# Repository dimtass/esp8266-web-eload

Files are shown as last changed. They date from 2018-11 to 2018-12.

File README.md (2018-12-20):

esp8266-web-eload
---
This project is how to build an electronic load with a web interface
by using the esp8266-E12 module and some other electronic components.
This version is using the Arduino ESP8266 for simplicity, but I would
like to make this soon also baremetal and use the ESP API instead.

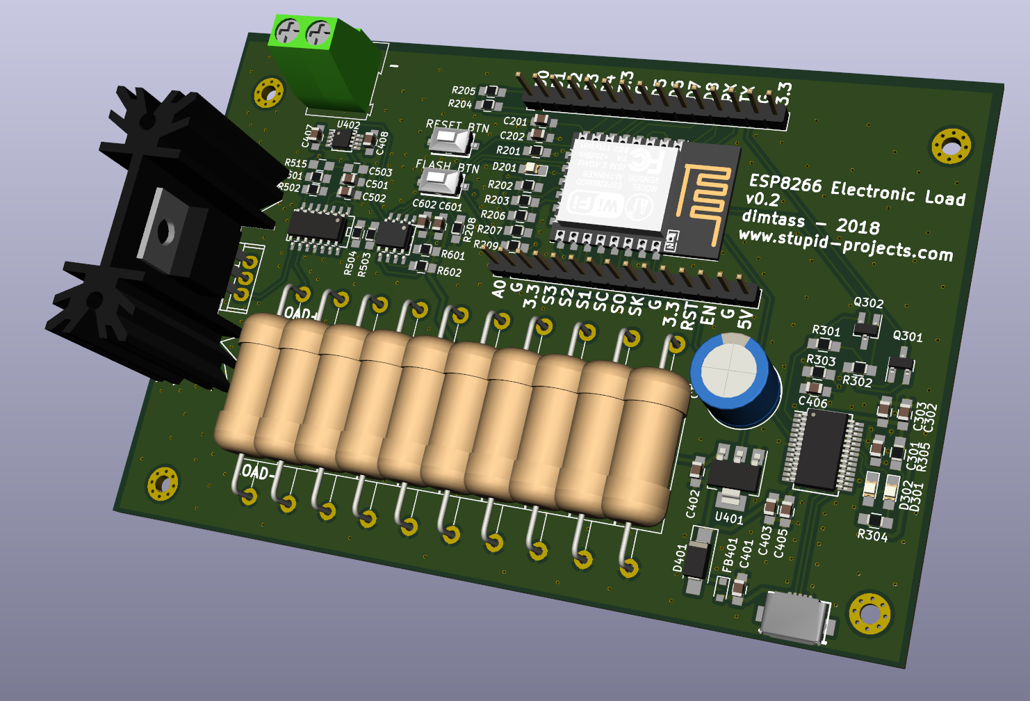
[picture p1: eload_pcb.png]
Electronic load board


## Board
You can also find the scematics to build a small pcb for that.
As you may already know, the esp8266 has a 10-bit ADC, but it lacks
a DAC. Therefore, we need an external SPI DAC. You can use any DAC
but as it is a home-project I prefer to use a bit more expensive
components.

The main components I've used are:
* `FDP6030BL`: N-Channel Logic Level MOSFET. This mosfet is features
40A, 30V, Rds(on)=0.024Ω @ Vgs=4.5V, 175oC max junction temp
* `MCP4821`: 12-bit SPI DAC with an internal Vref. This one has an
internal 2.048V reference and a 2x gain, therefore the Vref can be
up to 4.096V with a great accuracy. This means that we can drive the
Vgs on the MOSFET up to 4.096V, which means up to 4A with 1Ω load
resistor. If you need more current, then you can use the `MCP4921`
opamp which has an external reference, but that also means that you
need to provide a very clean and stable reference, too.
* `MCP6H04`: 4x single-supply, rail-to-rail opamp. This IC has four
opamps in the case. One is used to multiply the DAC output by a factor
of 2.2. One is used to drive the MOSFET and another one to buffer
the negative feedback loop to drive the ADC via a low pass RC filter
and a voltage divider with a 1/10 ratio.
* `FT232RL`: A USB to serial IC that is used for two reasons. One
is to power the circuit with 5V from the USB and the other is to
flash the esp8266. You need an IC that also has the DTR/RTS signals
in order to reset the board and put it into flash mode.

The DAC is 12-bit and it can take values 0-2.048V when the gain
is set to 1x or 0-4.096V when the gain is 2x. Also the ADC is 10-bits
with max input voltage 3V3, therefore it has 1024 steps. This means
that you need to use a voltage divider to feed the ADC.

## Build
You need to have the arduino IDE installed. I'm using Linux, so I'm
describing how to do that on Linux. First, download the IDE from
[here](https://www.arduino.cc/en/Main/Software). I usually prefer
specific versions because arduino IDE versions are known to be
incopatible with each other and some commands may not work between
versions. Therefore, for this project prefer to use version `1.8.6`
from [here](https://www.arduino.cc/download_handler.php?f=/arduino-1.8.6-linux64.tar.xz).
This is the x86_64 Linux version.

Extract the contents somewhere. I prefer `/opt`, for example
`/opt/arduino-1.8.6`.

Then open a console and run these commands:
```sh
mkdir -p ~/Arduino/hardware/esp8266com
cd ~/Arduino/hardware/esp8266com
git clone https://github.com/esp8266/Arduino.git esp8266
cd esp8266/tools
python get.py
/opt/arduino-1.8.6/arduino --install-boards esp8266:esp8266 --save-prefs
```

Then run the Arduino IDE and click `Tools -> Manage Libraries` and search
for the `websockets by Markus Sattler` library and select version `2.1.1`.
Then exit the Arduino IDE and from the source code folder run:
```sh
./build.sh
```

If your arduino IDE is not installed in `/opt/arduino-1.8.6` or you're
using a different version then you need to edit the `build.sh` script
and change the `ARDUINO=` variable with the correct path.

If everything goes right then you should have a folder named `build` and
inside that fodler a file named `esp8266-web-eload.ino.bin`.

Then connect you esp8266-E12 board with a USB cable on your computer and
verify which port is enumerated on it
```sh
dmesg | grep tty
```

Usually it will be the last port listed after you run the above command.

Finally, run the `upload-http-files.sh` script with the port you've found:
```sh
./upload-http-files.sh /dev/ttyUSB0
```

You might need to change the paths of the `mkspiffs` and `esptool` for the
script to work properly. If you want to be able to upload the web interface
from the Arduino IDE, then have a look to this plugin [here](https://github.com/esp8266/arduino-esp8266fs-plugin).
This will integrate this functionality in the IDE. I'm using the script
as it flashes everything on one go, but for development you don't have
to upload everything, so if you just change something in the code and the
web interface remains the same or the opposite, then better use the IDE.

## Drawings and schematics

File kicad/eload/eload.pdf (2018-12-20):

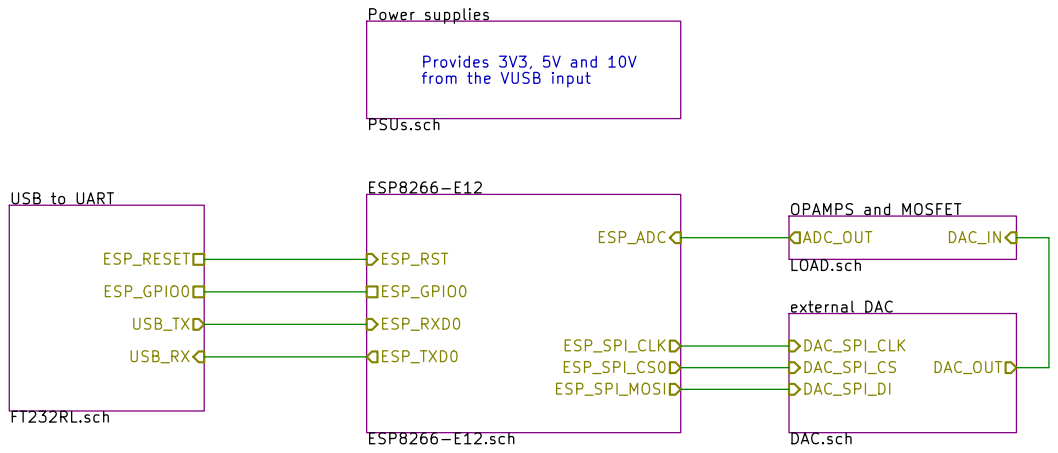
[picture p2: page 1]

from the VUSB input

This project uses a USB powered ESP8266, a DAC, a few opamps
and a N-MOSFET to create an electronic load. The source code
is available at:

Id: 1/6 Title: File: eload.sch Sheet: /
Electronic load using an ESP8266 and external DAC

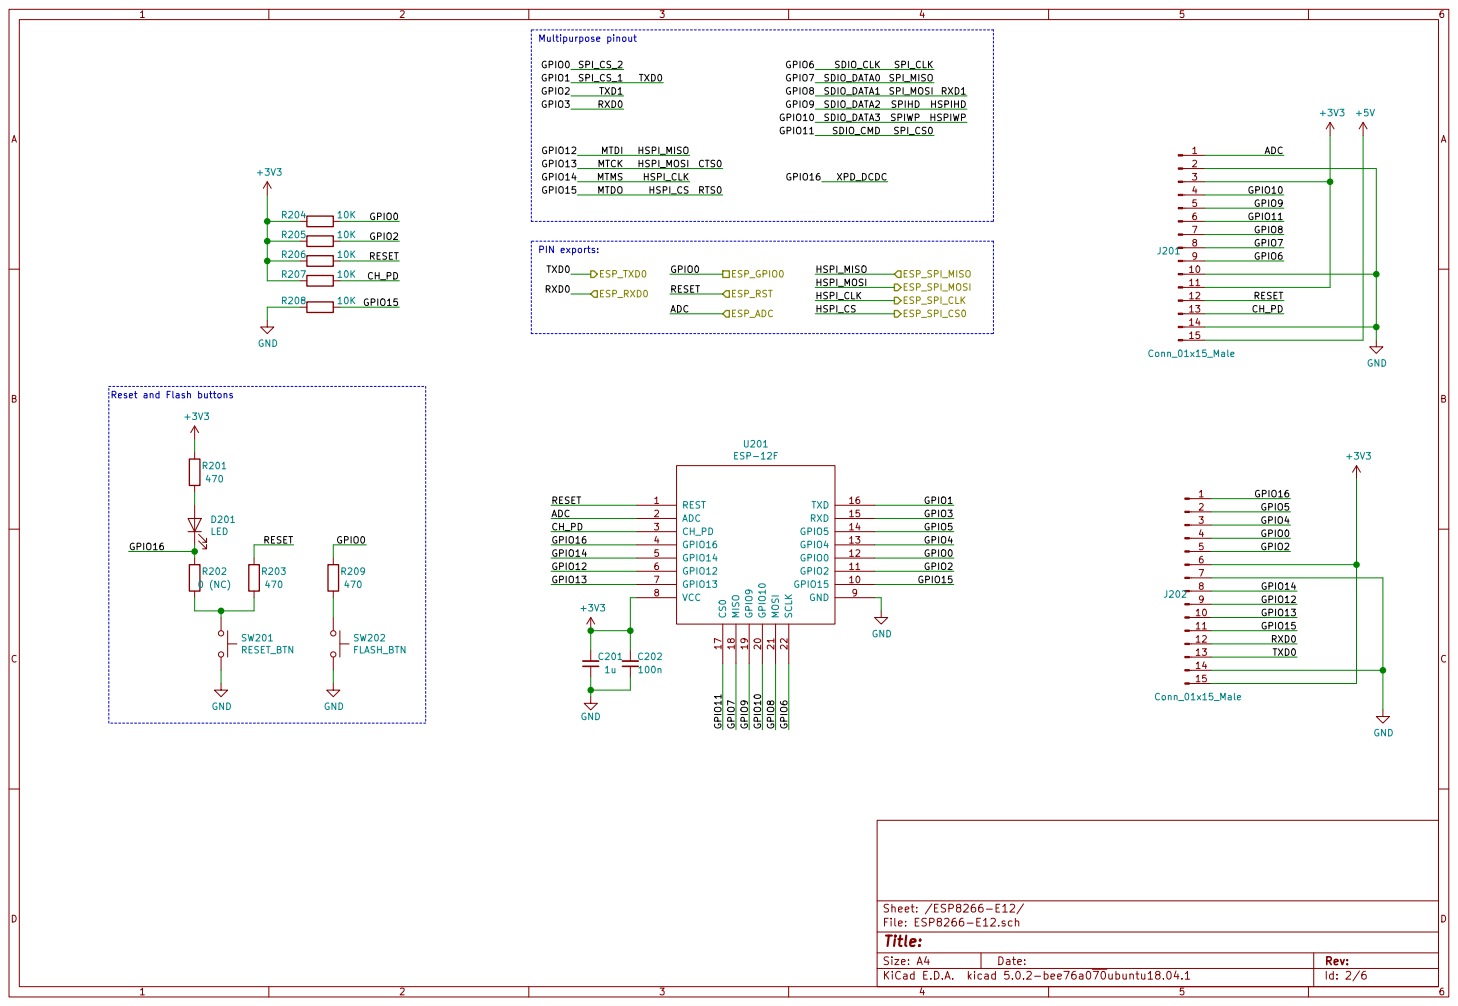
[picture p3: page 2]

Id: 2/6 Title: File: ESP8266-E12.sch Sheet: /ESP8266-E12/

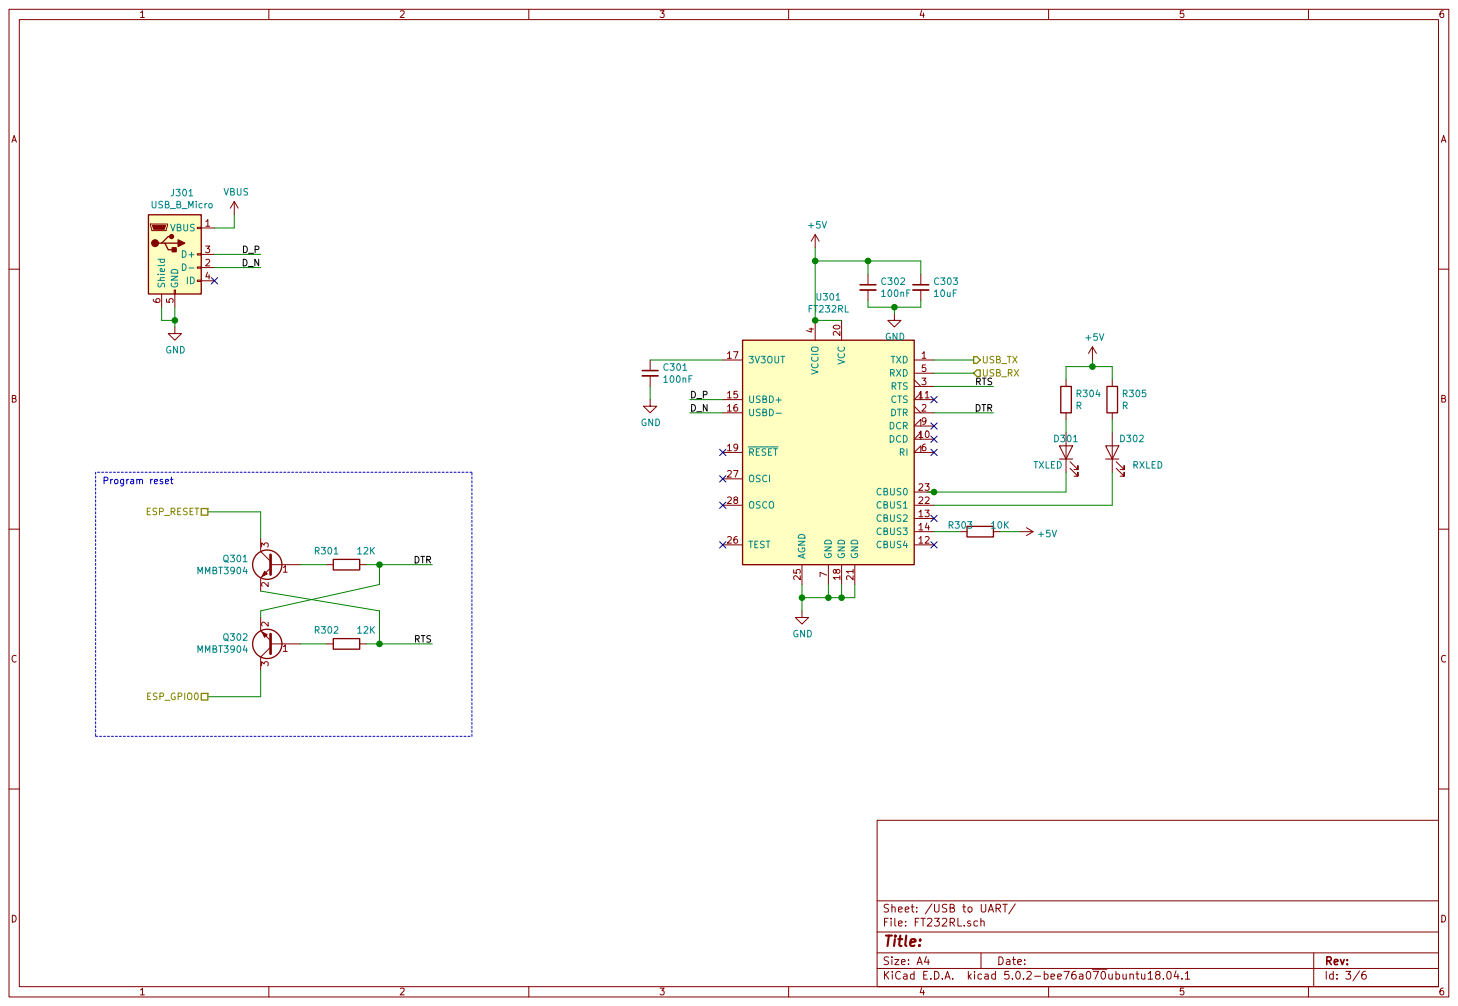
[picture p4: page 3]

Id: 3/6 Title: File: FT232RL.sch Sheet: /USB to UART/

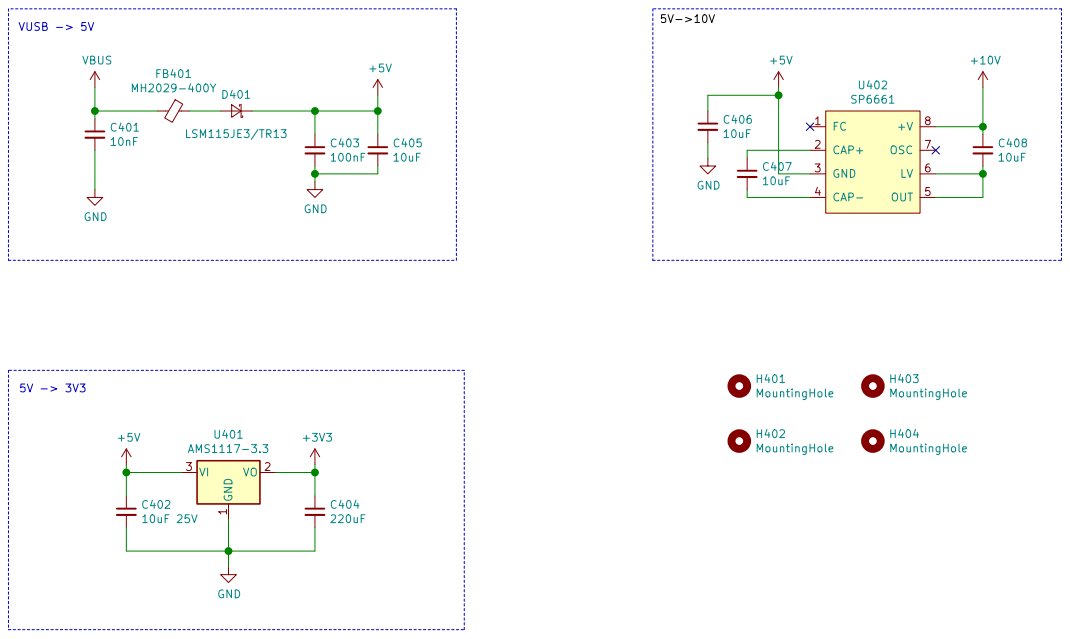
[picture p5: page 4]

Id: 4/6 Title: File: PSUs.sch Sheet: /Power supplies/

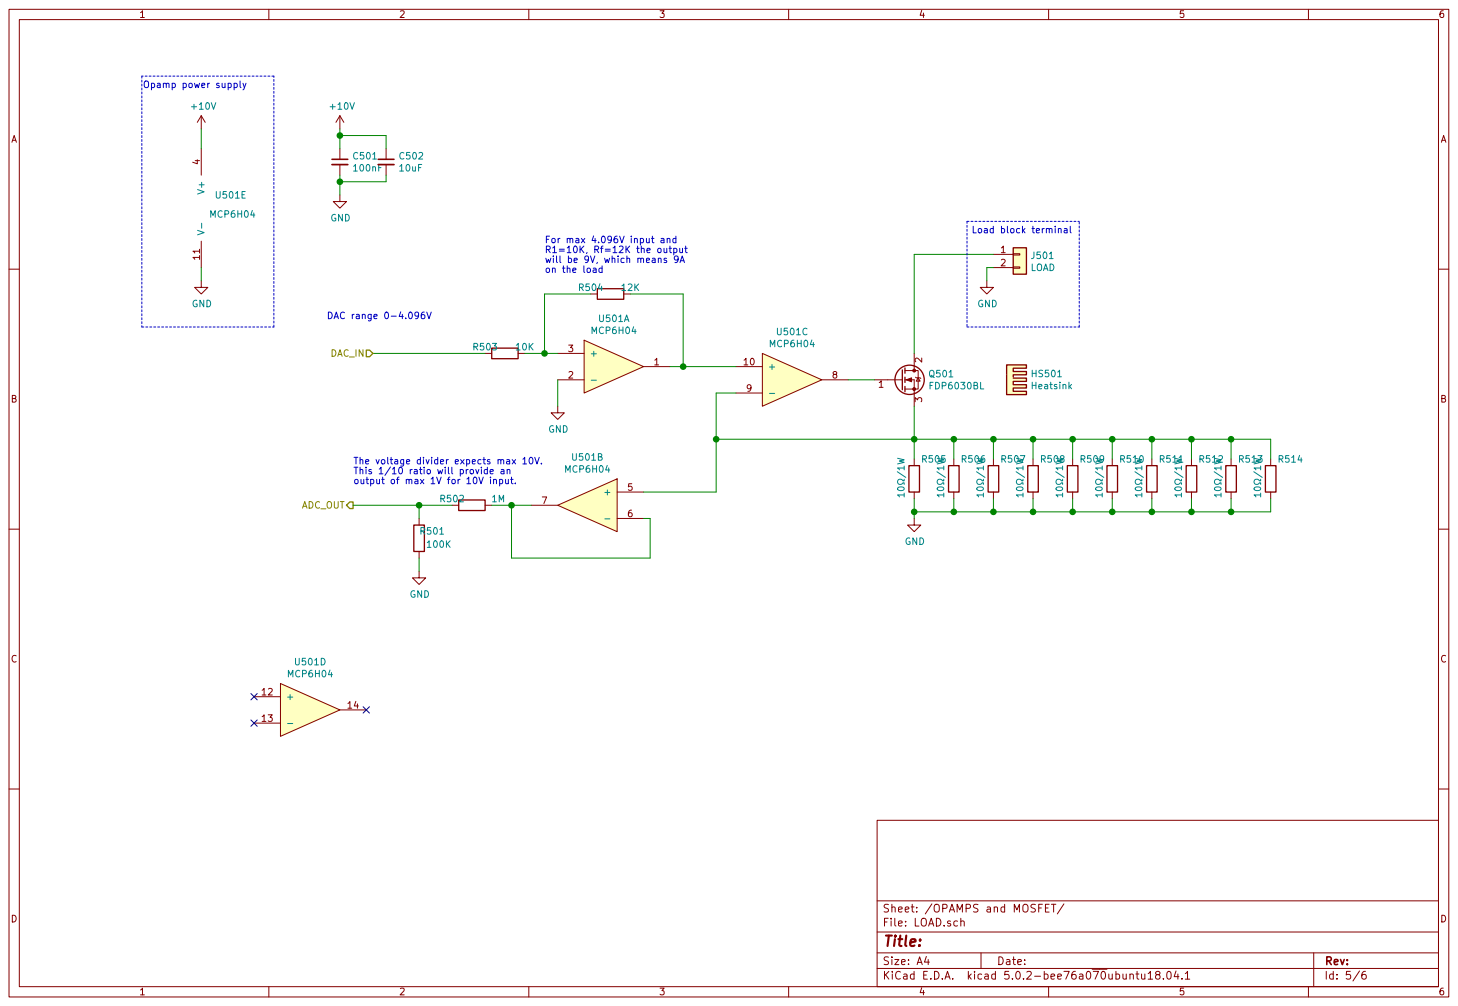
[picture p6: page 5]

Load block terminal DAC range 0-4.096V

For max 4.096V input and
R1=10K, Rf=12K the output will be 9V, which means 9A

The voltage divider expects max 10V.
This 1/10 ratio will provide an

Id: 5/6 Title: File: LOAD.sch Sheet: /OPAMPS and MOSFET/

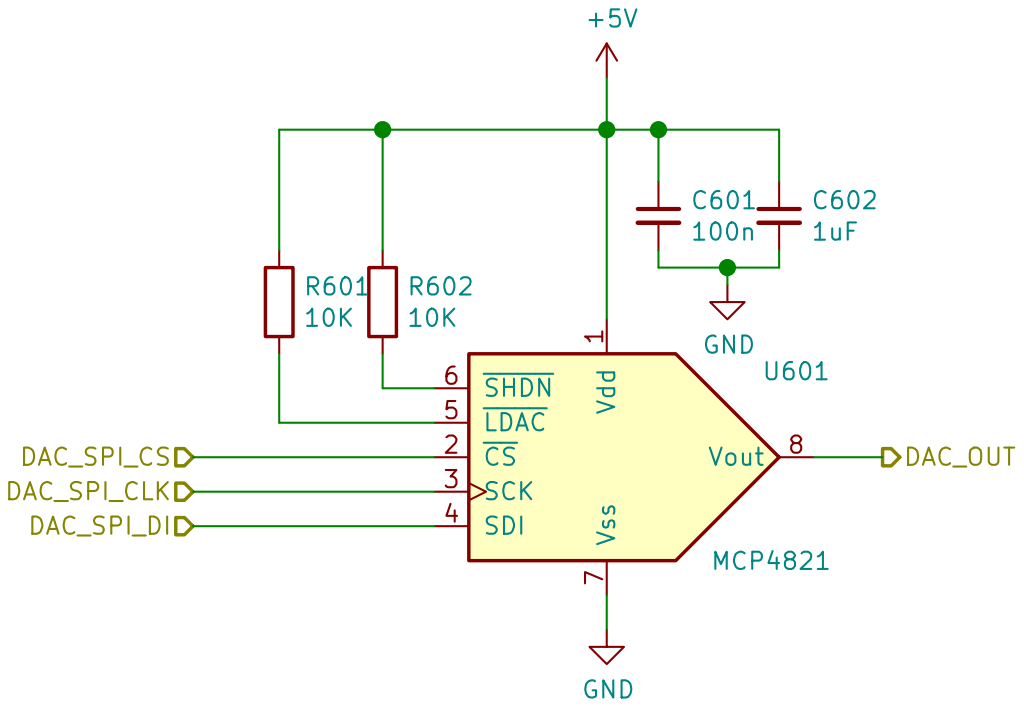
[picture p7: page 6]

Id: 6/6 Title: File: DAC.sch Sheet: /external DAC/ Vdd

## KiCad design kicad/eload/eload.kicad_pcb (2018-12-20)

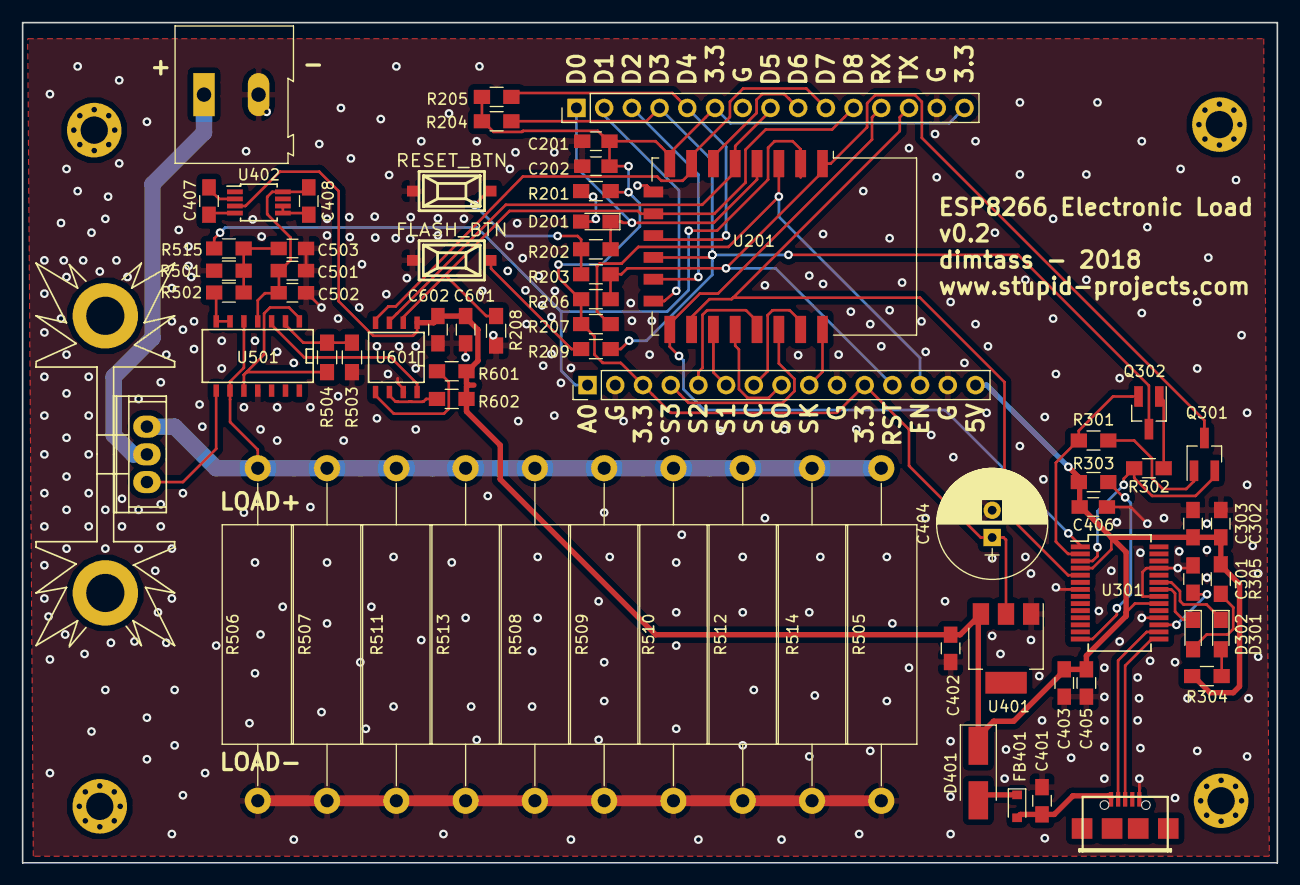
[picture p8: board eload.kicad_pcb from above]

Board: 2 copper layers, 115.0 x 77.0 mm, 74 parts (0 on the bottom side), 54 nets.

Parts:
C201: 1u; C_0805_HandSoldering
C202, C601: 100n; C_0805_HandSoldering
C301, C302, C403, C501: 100nF; C_0805_HandSoldering
C303, C405, C406, C407, C408, C502, C503: 10uF; C_0805_HandSoldering
C401: 10nF; C_0805_HandSoldering
C402: 10uF 25V; C_0805_HandSoldering
C404: 220uF; CP_Radial_D10.0mm_P2.50mm
C602: 1uF; C_0805_HandSoldering
D201: LED; LED_0805_HandSoldering
D301: TXLED; LED_0805_HandSoldering
D302: RXLED; LED_0805_HandSoldering
D401: LSM115JE3/TR13; D_SMA_Handsoldering
FB401: MH2029-400Y; D_0805
H401, H402, H403, H404: MountingHole; MountingHole_2.5mm_Pad_Via
HS501: Heatsink; Heatsink_Fischer_SK104-STCB_35x13mm__2xDrill3.5mm_ScrewM3
J201, J202: Conn_01x15_Male; Pin_Header_Straight_1x15_Pitch2.54mm
J301: USB_B_Micro; conn_usb_B_micro_smd-3
J501: LOAD; TerminalBlock_Altech_AK300-2_P5.00mm
Q301, Q302: MMBT3904; SOT-23_Handsoldering
Q501: FDP6030BL; TO-220
R201, R203, R209: 470; R_0805_HandSoldering
R202: 0 (NC); R_0805_HandSoldering
R204, R205, R206, R207, R208, R303, R502, R503, R601, R602: 10K; R_0805_HandSoldering
R301, R302, R504: 12K; R_0805_HandSoldering
R304, R305: R; R_0805_HandSoldering
R501: 1K; R_0805_HandSoldering
R505, R506, R507, R508, R509, R510, R511, R512, R513, R514: 10Ω/1W; R_Axial_Power_L20.0mm_W6.4mm_P30.48mm
R515: 15K; R_0805_HandSoldering
SW201: RESET_BTN; smd_push
SW202: FLASH_BTN; smd_push
U201: ESP-12F; ESP-12E
U301: FT232RL; SSOP-28_5.3x10.2mm_Pitch0.65mm
U401: AMS1117-3.3; SOT-223
U402: SP6661; MSOP-8_3x3mm_Pitch0.65mm
U501: MCP6H04; SOIC-14_N
U601: MCP4821; SOIC-8-N

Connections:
+3V3: C201.2, C202.2, C404.1, J201.3, J201.11, J202.6, J202.15, R201.1, R204.2, R205.2, R206.2, R207.2, U201.8, U401.2
+5V: C302.1, C303.1, C402.1, C403.1, C405.1, C406.1, C601.1, C602.1, D401.1, J201.15, R303.1, R304.1, R305.1, R601.1, R602.1, U301.4, U301.20, U401.3, U402.3, U601.1
+10V: C408.1, C501.1, C502.1, U402.8, U501.4
/ESP8266-E12/CH_PD: J201.13, R207.1, U201.3
/ESP8266-E12/ESP_GPIO0: J202.4, Q302.3, R204.1, R209.1, U201.12
/ESP8266-E12/ESP_RXD0: J202.12, U201.15, U301.1
/ESP8266-E12/ESP_SPI_MISO: J202.9, U201.6
/ESP8266-E12/ESP_TXD0: J202.13, U201.16, U301.5
/ESP8266-E12/GPIO2: J202.5, R205.1, U201.11
/ESP8266-E12/GPIO4: J202.3, U201.13
/ESP8266-E12/GPIO5: J202.2, U201.14
/ESP8266-E12/GPIO6: J201.9, U201.22
/ESP8266-E12/GPIO7: J201.8, U201.18
/ESP8266-E12/GPIO8: J201.7, U201.21
/ESP8266-E12/GPIO9: J201.5, U201.19
/ESP8266-E12/GPIO10: J201.4, U201.20
/ESP8266-E12/GPIO11: J201.6, U201.17
/ESP8266-E12/GPIO16: D201.1, J202.1, R202.1, U201.4
/OPAMPS and MOSFET/ADC_OUT: J201.1, R515.2, U201.2
/OPAMPS and MOSFET/DAC_IN: U501.3, U601.8
/USB to UART/DTR: Q302.2, R301.2, U301.2
/USB to UART/D_N: J301.2, U301.16
/USB to UART/D_P: J301.3, U301.15
/USB to UART/ESP_RESET: J201.12, Q301.3, R203.1, R206.1, U201.1
/USB to UART/RTS: Q301.2, R302.2, U301.3
/external DAC/DAC_SPI_CLK: J202.8, U201.5, U601.3
/external DAC/DAC_SPI_CS: J202.11, R208.1, U201.10, U601.2
/external DAC/DAC_SPI_DI: J202.10, U201.7, U601.4
GND: C201.1, C202.1, C301.2, C302.2, C303.2, C401.2, C402.2, C403.2, C404.2, C405.2, C406.2, C501.2, C502.2, C503.2, C601.2, C602.2, J201.2, J201.10, J201.14, J202.7, J202.14, J301.5, J501.2, R208.2, R501.1, R503.2, R505.2, R506.2, R507.2, R508.2, R509.2, R510.2, R511.2, R512.2, R513.2, R514.2, SW201.2, SW202.2, U201.9, U301.7, U301.18, U301.21, U301.25, U401.1, U501.11, U601.7
unnamed: C301.1, U301.17
unnamed: C407.1, U402.2
unnamed: C407.2, U402.4
unnamed: C408.2, U402.5, U402.6
unnamed: C503.1, R501.2, R502.2, R515.1
unnamed: D201.2, R201.2
unnamed: D301.1, U301.23
unnamed: D301.2, R304.2
unnamed: D302.1, U301.22
unnamed: D302.2, R305.2
unnamed: D401.2, FB401.1
unnamed: J501.1, Q501.2
unnamed: Q301.1, R301.1
unnamed: Q302.1, R302.1
unnamed: Q501.1, U501.8
unnamed: Q501.3, R505.1, R506.1, R507.1, R508.1, R509.1, R510.1, R511.1, R512.1, R513.1, R514.1, U501.5, U501.9
unnamed: R202.2, R203.2, SW201.1
unnamed: R209.2, SW202.1
unnamed: R303.2, U301.14
unnamed: R502.1, U501.6, U501.7
unnamed: R503.1, R504.2, U501.2
unnamed: R504.1, U501.1, U501.10
unnamed: R601.2, U601.5
unnamed: R602.2, U601.6
VBUS: C401.1, FB401.2, J301.1

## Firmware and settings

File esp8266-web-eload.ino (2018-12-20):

#include "Arduino.h"
#include <WebSocketsServer.h>
#include <FS.h>
#include <SPI.h>
#include "HelperFunctions.h"

int adc_value = 0;
int adc_acc = 0;
int acc = 0;
String inData;


//The setup function is called once at startup of the sketch
void setup()
{
	Serial.begin(115200);
	delay(1000);
	SPIFFS.begin();
	Serial.println(); Serial.print("Configuring access point...");
	setupWiFi();
	IPAddress myIP = WiFi.softAPIP();
	Serial.print("AP IP address: "); Serial.println(myIP);

	/* setup SPI */
	pinMode(CS, OUTPUT);                                       //configure the line as output
	digitalWrite(CS, HIGH);                                    //Initialize the CS line to HIGH
	delay(1000);
	SPI.begin();
	SPI.beginTransaction(SPISettings(1000000, MSBFIRST, SPI_MODE0));
	SPI.pins(14, 7, 8, 15);

	/* setup dac */
	dac.setWriteMode(MCP4x21::WRITE_ENABLE);
	dac.setBufferMode(MCP4x21::UNBUFFERED);
	dac.setPowerMode(MCP4x21::ACTIVE);
	dac.setOutputGain(MCP4x21::OUTPUT_GAIN_X2);

	/* By default is 0 */
	spiSendDAC(0);

	server.on("/", HTTP_GET, []() {
	  handleFileRead("/");
	});

	server.onNotFound([]() {                          // Handle when user requests a file that does not exist
	  if (!handleFileRead(server.uri()))
		server.send(404, "text/plain", "FileNotFound");
	});

	webSocket.begin();                                // start webSocket server
	webSocket.onEvent(webSocketEvent);                // callback function

	server.begin();
	Serial.println("HTTP server started");
	yield();
}

// The loop function is called in an endless loop
void loop() {
    static unsigned long l,l1 = 0;                     // only initialized once
    unsigned long t,t1;                                // local var: type declaration at compile time

    /* Every 6 msec read the ADC value and do a low pass filtering
     * by taking the average of 32 samples. That's a 32*6=192 msec
     * for each sample. Don't try to read the ADC in the while loop
     * without a timer because this will make the WiFi break.
     */
    t1 = millis();
    if((t1 - l1) > 6) {
        l1 = t1;
        adc_acc += analogRead(A0);
        yield();
        if ((acc++) >= 32) {
          adc_value = adc_acc >> 5; // divide by 32
          acc = 0;
          adc_acc = 0;
        }
    }

    /* Every 200 msec update the web interface with the ADC value */
    t = millis();
    if((t - l) > 200) {                           // update temp every 1 second
        webSocket.sendTXT(socketNumber, "#adc=" + String(adc_value));
        l = t;                                      // typical runtime this IF{} == 300uS - 776uS measured
        Serial.print("ADC:");Serial.println(adc_value);
        yield();
    }

    /* Read the UART for DAC values with a \r\n termination.
     * You just need to send the value, e.g.:
     *  1024\r\n
     *  4095\r\n
     * Min value: 0
     * Max value: 4095
     */
    while (Serial.available() > 0)
    {
        char recieved = Serial.read();
        inData += recieved; 

        // Process message when new line character is recieved
        if (recieved == '\n')
        {
            Serial.print("CAD: ");
            Serial.print(inData);
            spiSendDAC(inData.toInt());
            inData = ""; // Clear recieved buffer
        }
    }

    server.handleClient();
    webSocket.loop();
}

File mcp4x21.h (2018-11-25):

/*
 * mcp4x21.h
 *
 *  Created on: Nov 23, 2018
 *      Author: Dimitris Tassopoulos
 */

#ifndef MCP4X21_H_
#define MCP4X21_H_

#include <stdint.h>

class MCP4x21 {
public:
	enum en_adc_bits {
	    ADC_BITS_12 = 0,
	    ADC_BITS_10 = 2,
	    ADC_BITS_8 = 4
	};

	enum en_output_gain {
	    OUTPUT_GAIN_X2 = 0,
	    OUTPUT_GAIN_X1
	};

	enum en_power_mode {
	    SHUTDOWN = 0,
	    ACTIVE = 1
	};

	enum en_write_mode {
	    WRITE_ENABLE = 0,
	    WRITE_DISABLE = 1
	};

	enum en_buffer_mode {
	    UNBUFFERED = 0,
	    BUFFERED = 1
	};

	MCP4x21(MCP4x21::en_adc_bits bits);
	~MCP4x21();
	int setWriteMode(MCP4x21::en_write_mode mode);
	int setBufferMode(MCP4x21::en_buffer_mode);
	int setPowerMode(MCP4x21::en_power_mode);
	int setOutputGain(MCP4x21::en_output_gain);
	uint16_t setADC(uint16_t value);

private:
	struct tp_mcp4xx1_cmd {
	    /** 8/10/12-bit ADC data
	     * b11-b0: for 12-bit
	     * b11-b2: for 10-bit
	     * b11-b4: for 8-bit
	     */
	    uint16_t    data:12;
	    /** Output shutdown control bit
	     * 0: Shutdown the device
	     * 1: Active mode operation
	     */
	    uint8_t     shdn:1;
	    /** Output gain selection bit
	     * 0: 2x (Vout = 2*Vref * D/4096)
	     * 1: 1x (Vout = Vref * D/4096)
	     */
	    uint8_t     output_gain:1;
	    /** Vref Input buffer control bit
	     * 0: Unbuffered
	     * 1: Buffered
	     */
	    uint8_t     buf:1;
	    /** Write bit
	     * 0: Write to DAC register
	     * 1: Ignore this command
	     */
	    uint8_t     write:1;    // 0: Write to DAC, 1: ignore this command
	};

	union un_mcp4xx1_cmd {
	    uint16_t  __attribute__ ((aligned (16)))  raw;
	    struct tp_mcp4xx1_cmd cmd;
	};
	enum en_adc_bits m_bits;
	union un_mcp4xx1_cmd m_mcp_cmd;
};



#endif /* MCP4X21_H_ */

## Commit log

2018-12-03 Added kicad schematics
    [3V3_PSU.sch, DAC.sch, ESP8266-E12.sch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]
2018-12-03 kicad libraries change
2018-12-20 Version 0.2
    [ESP8266-E12.sch, LOAD.sch, PSUs.sch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]
2018-12-20 Added an RC filter in the ADC input
    [eload.kicad_pcb]
2018-12-20 Moved block terminal on top
    [eload-B.Cu.gbl, eload-B.Mask.gbs, eload-B.SilkS.gbo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]
2018-12-20 Convert adc points to volts
2018-12-20 Bug fixes
    [eload-calc.ods]
